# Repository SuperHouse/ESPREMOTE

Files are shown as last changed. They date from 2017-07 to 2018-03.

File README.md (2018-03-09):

ESPREMOTE: ESP8266 Remote Control Adapter
=========================================

Copyright 2017-2018 SuperHouse Automation Pty Ltd  www.superhouse.tv  

Allows an RF remote control to be connected to an ESP8266 so that it
can be triggered remotely as if the buttons were pushed.

Features:

 * ESP8266 MCU with wifi.
 * 4 low-side switched transistor outputs.
 * Headers for GND and 3.3V to power the remote control.
 * 2.1mm DC jack for 5-24Vdc power input.
 * Efficient 3.3V switchmode power supply.

Note: Images below are for old v1.0 release. Images need updating.

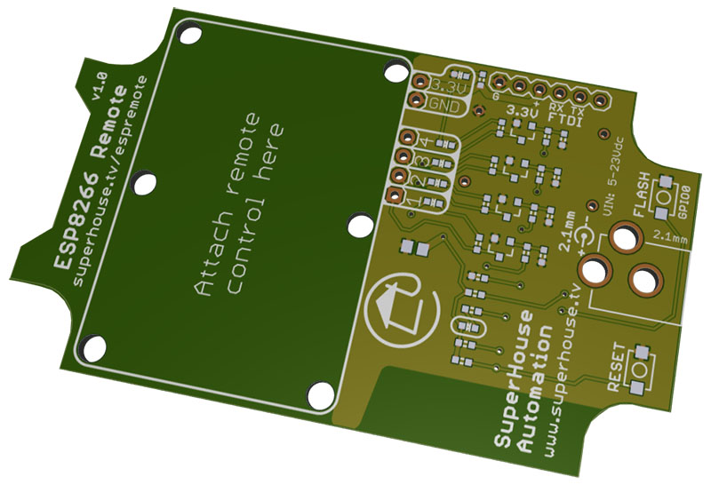
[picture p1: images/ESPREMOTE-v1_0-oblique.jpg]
Oblique view


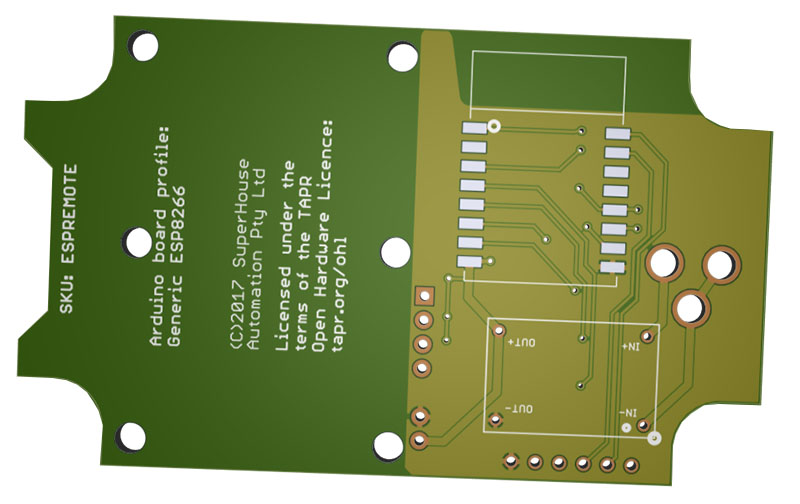
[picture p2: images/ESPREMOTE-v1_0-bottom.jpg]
Bottom view


More information is available at:

  http://www.superhouse.tv/espremote

INSTALLATION
------------
The design is saved as an EAGLE project. EAGLE PCB design software is
available from www.cadsoftusa.com free for non-commercial use. To use
this project download it and place the directory containing these files
into the "eagle" directory on your computer.

DISTRIBUTION
------------
The specific terms of distribution of this project are governed by the
license referenced below.

LICENSE
-------
Licensed under the TAPR Open Hardware License (www.tapr.org/OHL).
The "license" folder within this repository also contains a copy of
this license in plain text format.

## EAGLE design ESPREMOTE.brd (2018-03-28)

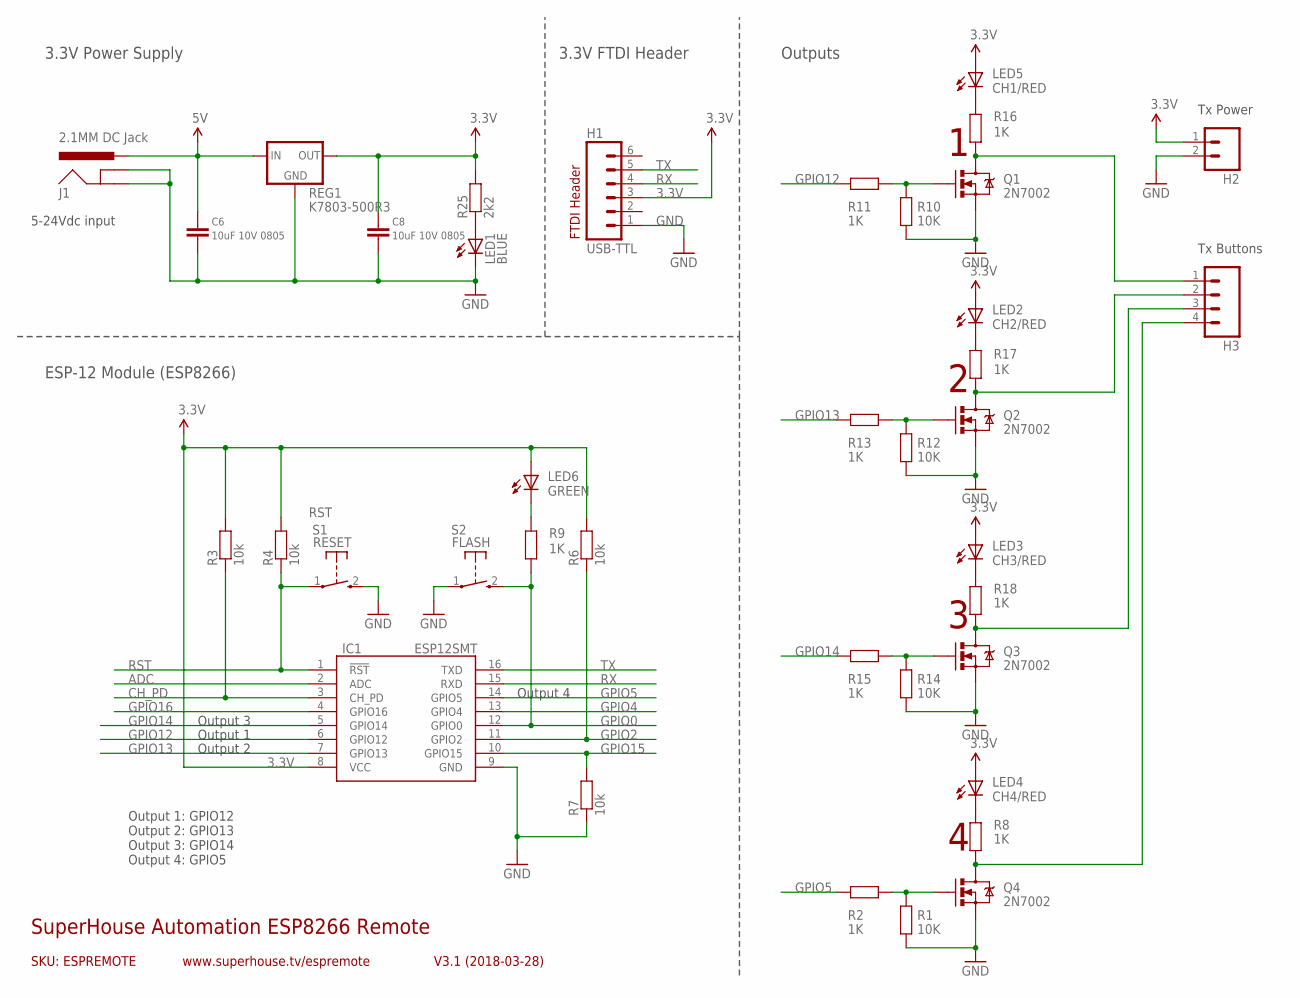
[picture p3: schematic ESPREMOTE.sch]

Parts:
C6, C8: 10uF 10V 0805; C0805
H1: USB-TTL; 1X06
H2: M02PTH; 1X02
H3: M04PTH; 1X04
IC1: ESP12SMT; ESP12
J1: 2.1MM DC Jack; POWER_JACK_PTH_SLOTS
LED1: BLUE; LED-0603
LED2: CH2/RED; LED-0603
LED3: CH3/RED; LED-0603
LED4: CH4/RED; LED-0603
LED5: CH1/RED; LED-0603
LED6: GREEN; LED-0603
Q1, Q2, Q3, Q4: 2N7002; SOT23-3
R1, R10, R12, R14: 10K; 0603
R2, R8, R9, R11, R13, R15, R16, R17, R18: 1K; 0603
R3, R4, R6, R7: 10k; 0603
R25: 2k2; 0603
REG1: K7803-500R3; K78XX-500R3
S1: RESET; TACTILE_SWITCH_SMD_2PIN_TINY
S2: FLASH; TACTILE_SWITCH_SMD_2PIN_TINY

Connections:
3.3V: C8.1, H1.3, H2.1, IC1.8 (VCC), LED2.A, LED3.A, LED4.A, LED5.A, LED6.A, R3.2, R4.2, R6.2, R25.2, REG1.3 (OUT)
5V: C6.1, J1.PWR, REG1.1 (IN)
ADC: IC1.2 (ADC)
CH_PD: IC1.3 (CH_PD), R3.1
GND: C6.2, C8.2, H1.1, H2.2, IC1.9 (GND), J1.GND, J1.GNDBREAK, LED1.C, Q1.2 (S), Q2.2 (S), Q3.2 (S), Q4.2 (S), R1.1, R7.1, R10.1, R12.1, R14.1, REG1.2 (GND), S1.2 (S), S2.1
GPIO0: IC1.12 (GPIO0), R9.2, S2.2 (S)
GPIO2: IC1.11 (GPIO2), R6.1
GPIO4: IC1.13 (GPIO4)
GPIO5: IC1.14 (GPIO5), R2.2
GPIO12: IC1.6 (GPIO12), R11.2
GPIO13: IC1.7 (GPIO13), R13.2
GPIO14: IC1.5 (GPIO14), R15.2
GPIO15: IC1.10 (GPIO15), R7.2
GPIO16: IC1.4 (GPIO16)
unnamed: Q1.1 (G), R10.2, R11.1
unnamed: Q2.1 (G), R12.2, R13.1
unnamed: H3.2, Q2.3 (D), R17.2
unnamed: LED3.C, R18.1
unnamed: H3.1, Q1.3 (D), R16.2
unnamed: H3.4, Q4.3 (D), R8.2
unnamed: Q4.1 (G), R1.2, R2.1
unnamed: H3.3, Q3.3 (D), R18.2
unnamed: Q3.1 (G), R14.2, R15.1
unnamed: LED4.C, R8.1
unnamed: LED2.C, R17.1
unnamed: LED1.A, R25.1
unnamed: LED5.C, R16.1
unnamed: LED6.C, R9.1
RST: IC1.1 (!RST), R4.1, S1.1
RX: H1.4, IC1.15 (RXD)
TX: H1.5, IC1.16 (TXD)

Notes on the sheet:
SKU: ESPREMOTE
SuperHouse Automation ESP8266 Remote
V3.1 (2018-03-28)
www.superhouse.tv/espremote
3.3V Power Supply
FTDI Header
Outputs
ESP-12 Module (ESP8266)
3.3V FTDI Header
5-24Vdc input
Output 1: GPIO12 Output 2: GPIO13 Output 3: GPIO14 Output 4: GPIO5
Output 1
Output 2
Output 3
Output 4
Tx Power
Tx Buttons

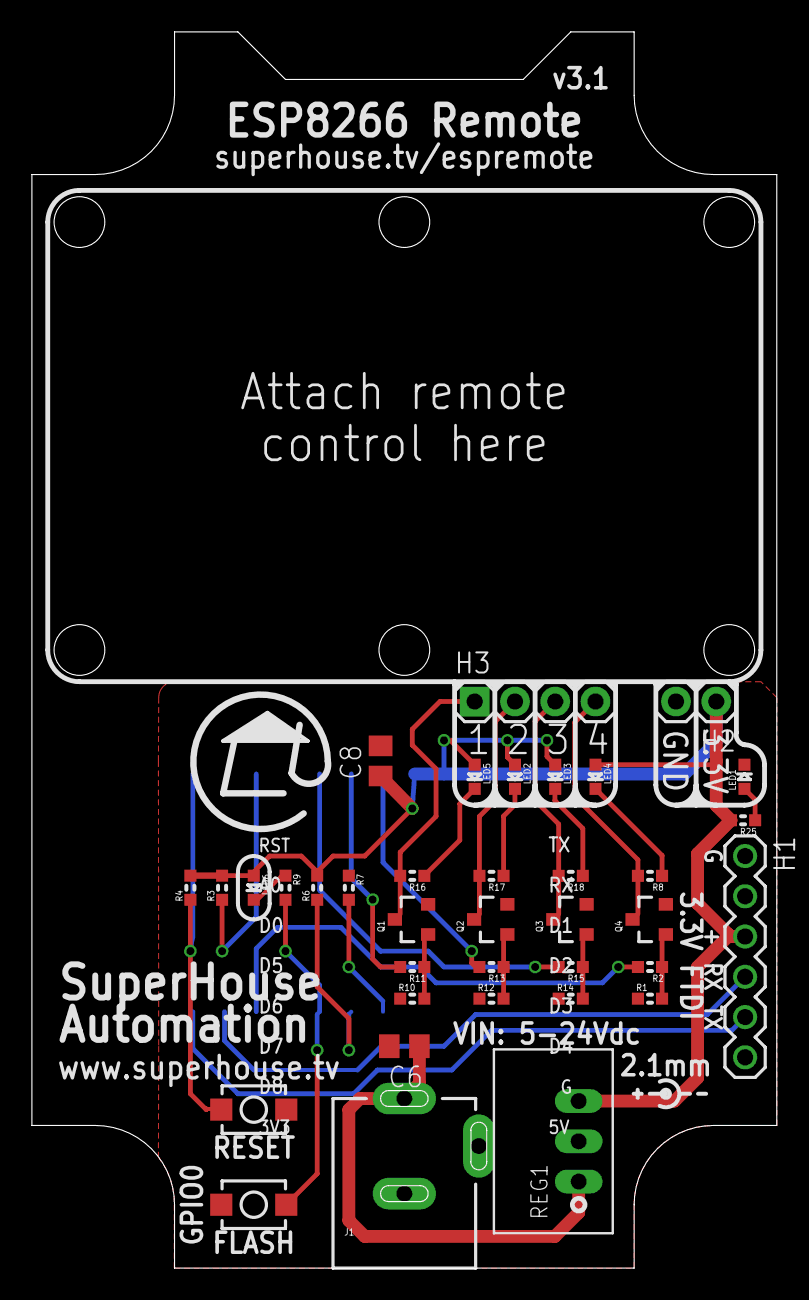
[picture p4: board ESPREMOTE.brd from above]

Board: 2 copper layers, 47.0 x 78.0 mm, 38 parts (1 on the bottom side), 28 nets.

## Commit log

2017-06-01 Initial project import after schematic and board layout
    [ESPREMOTE.brd, ESPREMOTE.sch]
2017-07-05 Finished schematic and routing for v1.0 release
    [ESPREMOTE.brd, ESPREMOTE.sch]
2017-07-29 Final silkscreen and label improvements for v1.0 release
    [ESPREMOTE.brd, ESPREMOTE.sch]
2017-07-29 Added output info to silkscreen
    [ESPREMOTE.brd, ESPREMOTE.sch]
2017-07-29 Changed output 4 from GPIO16 to GPIO4
    [ESPREMOTE.brd, ESPREMOTE.sch]
2017-07-30 Replaced 2.1mm DC jack and switchmode reg with USB socket and linear reg
    [ESPREMOTE.brd, ESPREMOTE.sch]
2018-03-09 Replaced crappy SMPS with linear reg and micro USB socket
    [ESPREMOTE.brd, ESPREMOTE.sch]
2018-03-09 Replaced USB socket and linear reg with 2.1mm DC jack and SMPS module
    [ESPREMOTE.brd, ESPREMOTE.sch]
2018-03-09 Improved labels for v3.0 release
    [ESPREMOTE.sch]
2018-03-28 Fixed ESP12 pinout for v3.1 release
    [ESPREMOTE.brd, ESPREMOTE.sch]

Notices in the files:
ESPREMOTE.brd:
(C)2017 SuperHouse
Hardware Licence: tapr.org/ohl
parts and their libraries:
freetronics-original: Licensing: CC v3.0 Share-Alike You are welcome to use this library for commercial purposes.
